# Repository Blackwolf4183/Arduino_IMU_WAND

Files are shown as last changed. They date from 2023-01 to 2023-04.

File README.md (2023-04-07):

# Project Report

# Smart House and Pattern Recognition based on RPI and ESP8266.

## Introduction

In this report I want to showcase a recent project I did to test some practical and not so practical applications on Machine Learning and real world interactions. 

The inspiration for this project came to me when I saw on an online video a Harry Potter’s wand made by Warner Bros, which you could use to perform some “spells” with and it would connect to your smarthome to, for instance, turn on you lights or audio.

I thought the idea was pretty interesting, but I didn’t know the technology they were using to detect the gestures and transform them into orders. 

Still without any knowledge at all about the insights of the wand I supposed It had to use some kind of data gathering and some machine learning algorithm to infer the gestures.

I looked back to a module I had been meaning to use for another project, the MP6050.  The MP6050 is an IMU (Inertial Measurement Unit), which can provide data such as acceleration and angular velocity. 

I thought maybe there was a chance that if a collected the data from the IMU and run it through a Machine Learning Algorithm it could give me back information about which kind of gesture was made.

## Overview of the plan

The basic idea was to stuff some electronics in a custom made wand, so I could transmit wirelessly data from the MP6050 to some kind of server and process that data.

The first challenge was the size of the wand. I have some prior experience with electronics and circuits but none of the kind of making custom PCBs with integrated circuits, so I had to think of the smallest components I could use to get this working. The list is as follows:

- Arduino nano
- ESP8266 - 01 Wifi Module
- On/Off Switch
- 3.7V Lipo Battery
- RGB LED
- LM 1117 (for current reduction to 3.3V)
- 4 330 Ohms Resistors
- Different color cables
- Small Button
- TP4056 (for Lipo charging and discharging)
- 16V 1000**μF** Capacitor

One I had the list of components I made some schematics for the circuit:

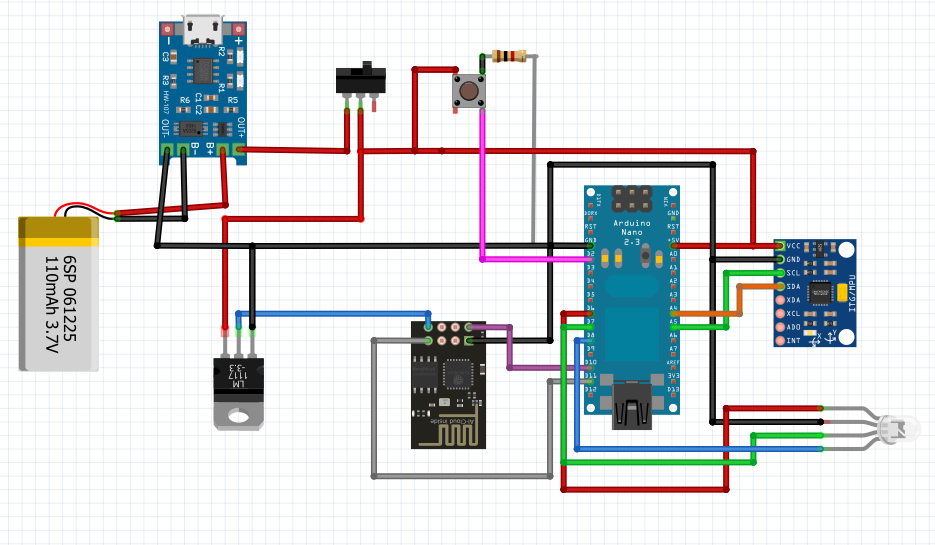
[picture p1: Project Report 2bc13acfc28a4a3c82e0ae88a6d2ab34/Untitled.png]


Having all those components at hand I figured a common size wand from the Harry Potter’s Universe wasn’t going to cut it for the size, so with the help of **Blender** ( 3D Modeling tool) , and a base model I took from a 3D printing website, I altered the model so everything could fit inside nicely.

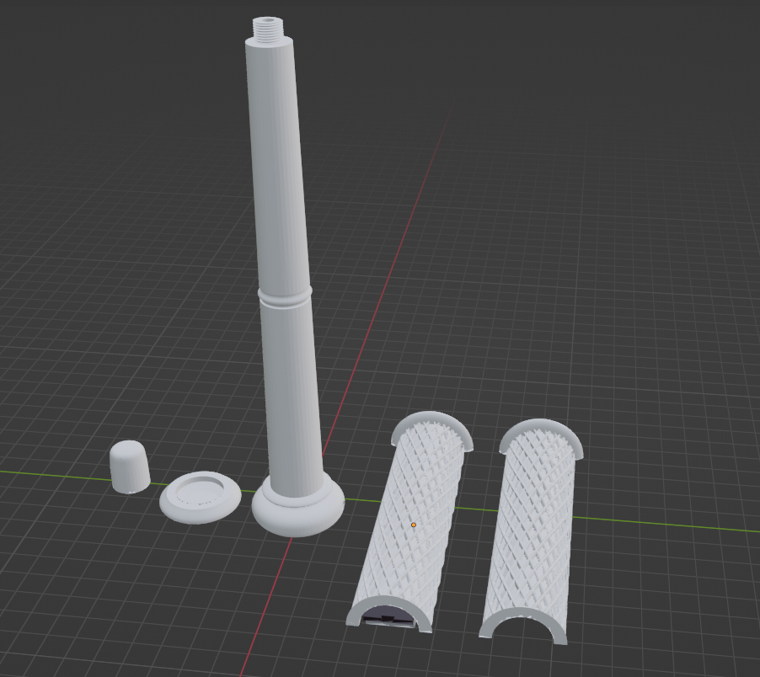
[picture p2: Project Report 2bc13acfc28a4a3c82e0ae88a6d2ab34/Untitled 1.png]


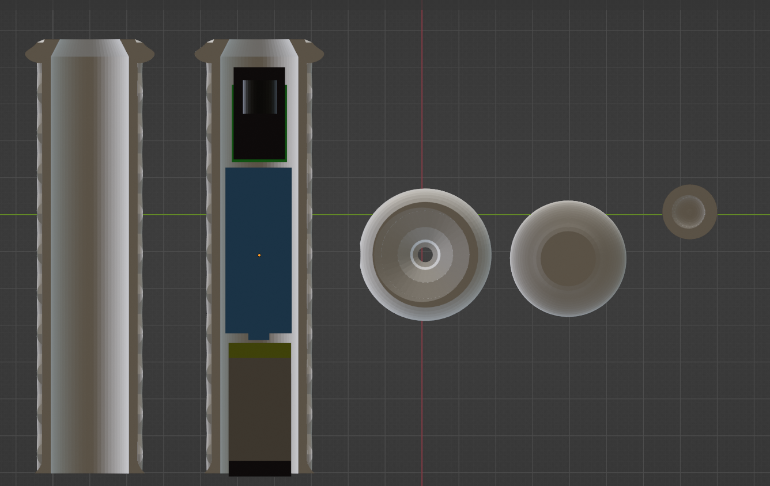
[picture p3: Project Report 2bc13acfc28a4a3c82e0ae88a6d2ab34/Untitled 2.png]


## Wireless Transmission System

The second challenge was to transmit all the data gathered by the wand trough my home wifi network into my **Raspberry Pi**, which would act as a server to manage al the data, and probably host a small webserver in the future. 

### Data format

Most Machine Learning algorithms work best with a fixed size input, so I had to think of a way to always have the same “amount” of data coming out of the ESP8266. The simplest solution to this was to have a button you would press in the wand so that it would start recording a particular amount of values. I estimated that a sequence of 20, 6 value vectors would suit my needs.

In the end I had sequenced that looked something like this:

|  | AccelerationX | AccelerationY | AccelerationZ | AngularX | AngularY | AngularZ |
| --- | --- | --- | --- | --- | --- | --- |
| t0 | 1.2234 | 9.862 | 4.5123 | 0.3523 | 12.903 | 1.643 |
| t1 | 2.2234 | 9.334 | 6.3456 | 0.3236 | 13.347 | 1.393 |
| t2 | 3.2345 | 9.646 | 7.2134 | 0.5523 | 14.384 | 2.234 |
| t3 | 2.2345 | 9.123 | 6.2345 | 0.6553 | 15.522 | 1.931 |
| t4 | 1.7856 | 9.002 | 5.3234 | 0.5563 | 16.332 | 1.000 |
| …. | ….. | …. | …. | … | … | … |
| t19 | 1.2345 | 9.005 | 6.2342 | 0.5523 | 16.342 | 1.123 |

### Setting up de Raspberry Pi

As mentioned earlier, the choice of “server” was the **Raspberry Pi 3B,** I decided to install Raspbian and run a MQTT mosquitto server on it. MQTT is a protocol used for machine-to-machine communication commonly seen in SmartHome applications.

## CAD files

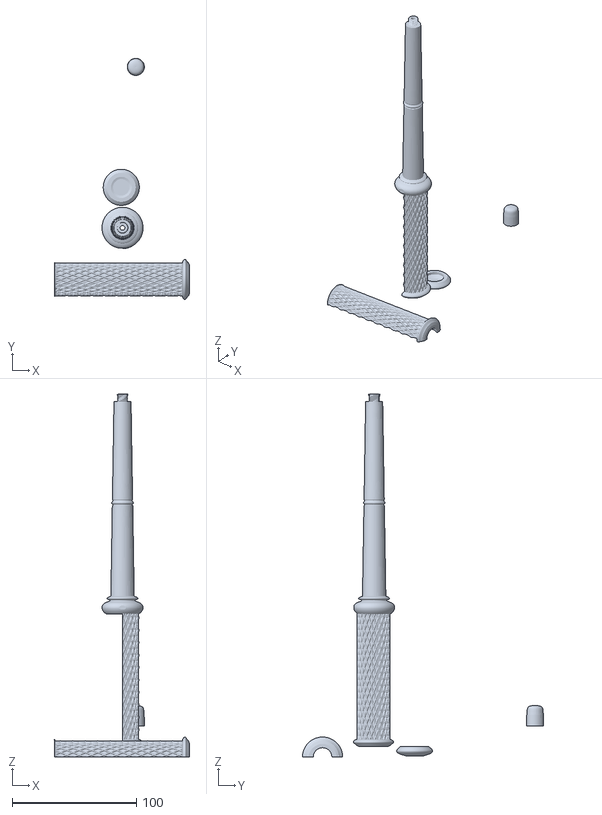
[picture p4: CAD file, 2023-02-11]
Electronics/Compartimento/TestFull.stl
108.7 x 194.2 x 292.3

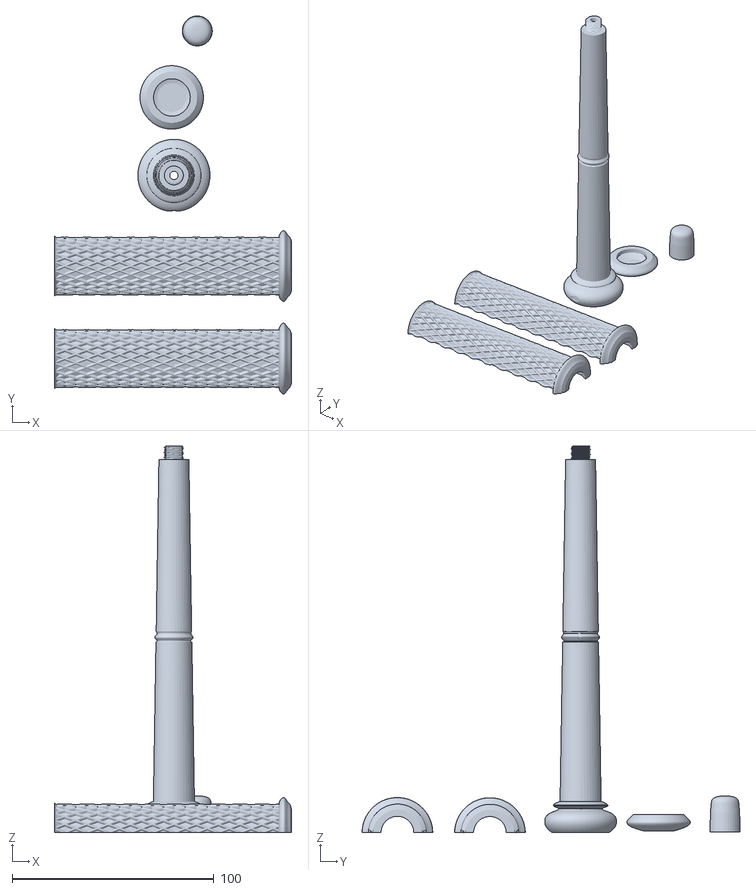
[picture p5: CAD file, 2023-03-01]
Electronics/Compartimento/17-02.stl
117.7 x 187.6 x 191.9

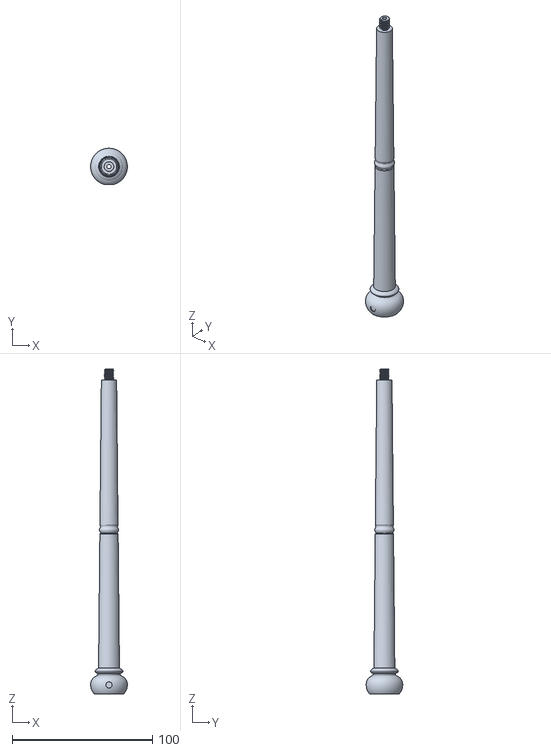
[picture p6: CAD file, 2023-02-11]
Electronics/Compartimento/14-TOP.stl
26.2 x 26.0 x 231.5

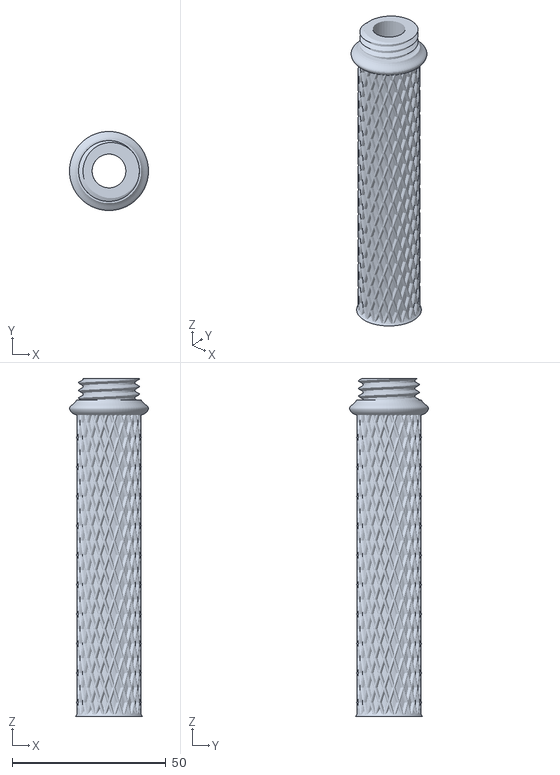
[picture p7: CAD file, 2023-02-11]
Electronics/Compartimento/14-HANDLE.stl
25.7 x 25.7 x 110.0

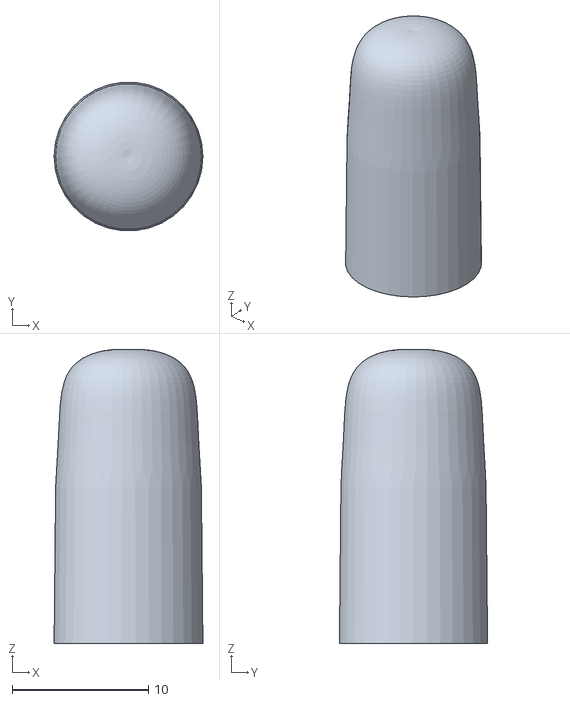
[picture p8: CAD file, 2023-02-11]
Electronics/Compartimento/14-TIP.stl
10.9 x 10.9 x 21.6

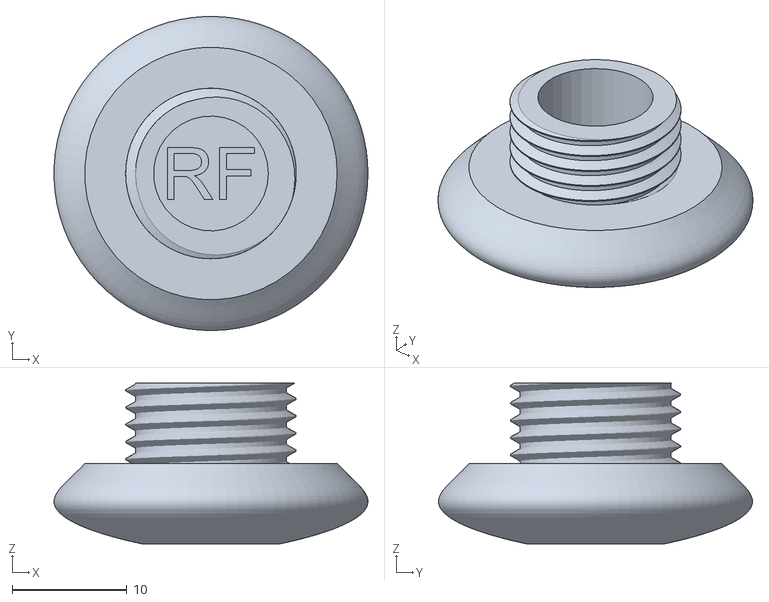
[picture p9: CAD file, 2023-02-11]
Electronics/Compartimento/14-BOTTOM.stl
27.3 x 27.3 x 14.0

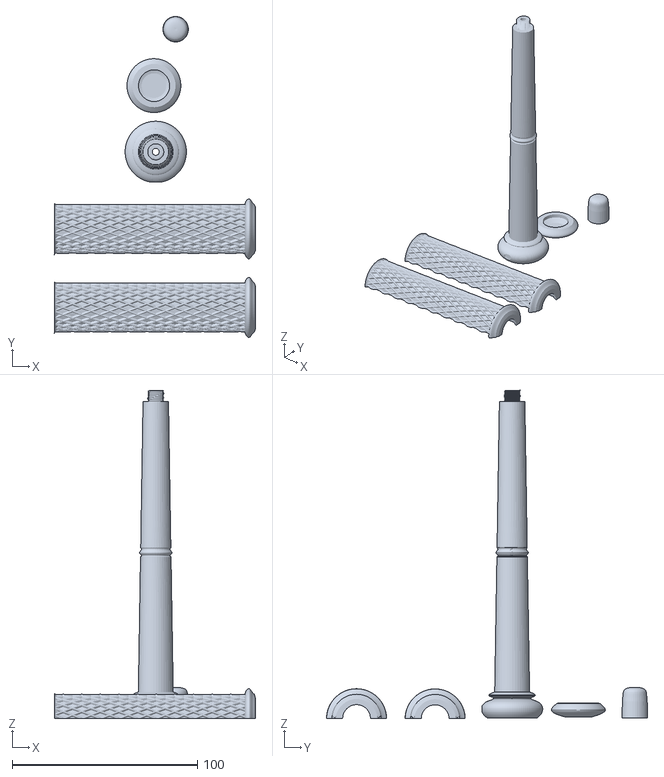
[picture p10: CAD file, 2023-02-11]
Electronics/Compartimento/Resized29.stl
108.7 x 173.2 x 177.2

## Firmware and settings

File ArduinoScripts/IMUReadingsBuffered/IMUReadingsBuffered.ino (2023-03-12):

#include <Adafruit_MPU6050.h>
#include <Adafruit_Sensor.h>
#include <Wire.h>
#include <SoftwareSerial.h>

#define STACK_SIZE 20

const int buttonPin = 2;
//RGB Led
const int redPin = 6;
const int greenPin = 7;
const int bluePin = 8;

//Counter for the amount of sequences sent
int counter = 0;

// Number of colors used for animating, higher = smoother and slower animation)
int numColors = 255;

//Counter to keep track of led color
int ledCounter = 0;
int buttonState = 0;
//Led to notify gesture recording
bool ledOn = false;
//Control wether pushing the button does anything at all
bool canPushButton = true;

Adafruit_MPU6050 mpu;

//Serial communication with Esp8266 Setup
SoftwareSerial mySerial(10, 11);  // RX, TX


//Timers
const unsigned long mainLoopInterval = 100;
const unsigned long rgbInterval = 8;

unsigned long mainLoopTimer;
unsigned long rgbTimer;

//Serial readings variables
const byte numChars = 3;
char receivedChars[numChars];   // an array to store the received data
boolean newData = false;

void setup(void) {

  Serial.println("Starting program...");

  //Timers
  mainLoopTimer = millis();
  rgbTimer = millis();

  //Pin outputs
  pinMode(buttonPin, INPUT);
  pinMode(redPin, OUTPUT);
  pinMode(greenPin, OUTPUT);
  pinMode(bluePin, OUTPUT);

  Serial.begin(115200);
  while (!Serial)
    delay(10);  // will pause Zero, Leonardo, etc until serial console opens


  // Try to initialize!
  if (!mpu.begin()) {
    Serial.println("Failed to find MPU6050 chip");
    while (1) {
      delay(10);
    }
  }
  Serial.println("MPU6050 Found!");

  //Stablish ranges
  mpu.setAccelerometerRange(MPU6050_RANGE_8_G);
  mpu.setGyroRange(MPU6050_RANGE_500_DEG);
  //21 Khz bandwitdh
  mpu.setFilterBandwidth(MPU6050_BAND_21_HZ);
  delay(100);


  //Serial Comunication with esp8266
  mySerial.begin(115200);
  mySerial.println("Starting conexion");
}



void loop() {


  if((millis() - mainLoopTimer) >= mainLoopInterval){

    /* Get new sensor events with the readings */
    //if recording
    if (ledOn) {
      sensors_event_t a, g, temp;
      mpu.getEvent(&a, &g, &temp);

      String values = "";
      values = String(a.acceleration.x) + "," + String(a.acceleration.y) + "," + String(a.acceleration.z) + "," + String(g.gyro.x) + "," + String(g.gyro.y) + "," + String(g.gyro.z);

      //Send over serial
      mySerial.println(values);
      counter++;

      Serial.println(counter);
      Serial.println(values);
      if (counter == STACK_SIZE) {
        //if buffer fills stop
        toggle_led();
        //restart counter
        counter = 0;
      }
      
    }

    //Button
    buttonState = digitalRead(buttonPin);

    if (buttonState == HIGH && canPushButton) {
      Serial.println("Button has been pushed");
      toggle_led();
      mySerial.println("Sequence");
    }


    //#########################################################
    //Serial reading
    recvWithEndMarker();
    
    if (newData == true) {
        Serial.println("Code received: ");
        Serial.println(receivedChars);

        /* 
        Response codes:
        - c1: Operation succesfull
        - c2: Error ocurred
        - c3: Lumos command for wand 
        
        */


        if(!strncmp(receivedChars, "c1",numChars)){
            setColor(0, 255, 0);
            delay(500);
            setColor(0, 0, 0);
            delay(500);
            setColor(0, 255, 0);
            delay(500);
            setColor(0, 0, 0);
            delay(500);
            setColor(0, 255, 0);
            delay(500);
            setColor(0, 0, 0);
 
      
        }else if(!strncmp(receivedChars, "c2",numChars)){
            setColor(255, 0, 0);
            delay(300);
            setColor(0, 0, 0);
            delay(300);
            setColor(255, 0, 0);
            delay(300);
            setColor(0, 0, 0);
            delay(300);
            setColor(255, 0, 0);
            delay(300);
            setColor(0, 0, 0);
            
        }else if(!strncmp(receivedChars, "c3",numChars)){
          setColor(255, 255, 255);
          delay(4000);
          setColor(0, 0, 0);
        }

        newData = false;
    }

    //############################################

    mainLoopTimer = millis();
  }

  if((millis() - rgbTimer) >= rgbInterval){
    //RGB Led
    if(ledOn){
      float colorNumber = ledCounter > numColors ? ledCounter - numColors: ledCounter;
      
      //Led Brightness
      float brightness = 1; // Between 0 and 1 (0 = dark, 1 is full brightness)
      float saturation = 1; // Between 0 and 1 (0 = gray, 1 = full color)
      float hue = (colorNumber / float(numColors)) * 360; // Number between 0 and 360
      long color = HSBtoRGB(hue, saturation, brightness); 
      
      // Get the red, blue and green parts from generated color
      int red = color >> 16 & 255;
      int green = color >> 8 & 255;
      int blue = color & 255;

      setColor(red, green, blue);
      
      // Counter can never be greater then 2 times the number of available colors
      // the colorNumber = line above takes care of counting backwards (nicely looping animation)
      // when counter is larger then the number of available colors
      ledCounter = (ledCounter + 1) % (numColors * 2);
    }else{
      //If led not on just no color
      setColor(0,0,0);
    }

    rgbTimer = millis();
  }

  
}

//Toggle LED
void toggle_led() {
  ledOn = canPushButton;
  canPushButton = !canPushButton;
}

//Set RGB Led Color
void setColor(int redValue, int greenValue, int blueValue) {
  analogWrite(redPin, redValue);
  analogWrite(greenPin, greenValue);
  analogWrite(bluePin, blueValue);
}

long HSBtoRGB(float _hue, float _sat, float _brightness) {
    float red = 0.0;
    float green = 0.0;
    float blue = 0.0;
    
    if (_sat == 0.0) {
        red = _brightness;
        green = _brightness;
        blue = _brightness;
    } else {
        if (_hue == 360.0) {
            _hue = 0;
        }

        int slice = _hue / 60.0;
        float hue_frac = (_hue / 60.0) - slice;

        float aa = _brightness * (1.0 - _sat);
        float bb = _brightness * (1.0 - _sat * hue_frac);
        float cc = _brightness * (1.0 - _sat * (1.0 - hue_frac));
        
        switch(slice) {
            case 0:
                red = _brightness;
                green = cc;
                blue = aa;
                break;
            case 1:
                red = bb;
                green = _brightness;
                blue = aa;
                break;
            case 2:
                red = aa;
                green = _brightness;
                blue = cc;
                break;
            case 3:
                red = aa;
                green = bb;
                blue = _brightness;
                break;
            case 4:
                red = cc;
                green = aa;
                blue = _brightness;
                break;
            case 5:
                red = _brightness;
                green = aa;
                blue = bb;
                break;
            default:
                red = 0.0;
                green = 0.0;
                blue = 0.0;
                break;
        }
    }

    long ired = red * 255.0;
    long igreen = green * 255.0;
    long iblue = blue * 255.0;
    
    return long((ired << 16) | (igreen << 8) | (iblue));
}



void recvWithEndMarker() {
    static byte ndx = 0;
    char endMarker = '\n';
    char rc;
    
    while (mySerial.available() > 0 && newData == false) {
        rc = mySerial.read();

        if (rc != endMarker) {
            receivedChars[ndx] = rc;
            ndx++;
            if (ndx >= numChars) {
                ndx = numChars - 1;
            }
        }
        else {
            receivedChars[ndx] = '\0'; // terminate the string
            ndx = 0;
            newData = true;
        }
    }
}

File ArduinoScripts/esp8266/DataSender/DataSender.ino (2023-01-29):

/*
  Rui Santos
  Complete project details at Complete project details at https://RandomNerdTutorials.com/esp8266-nodemcu-http-get-post-arduino/

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
  Code compatible with ESP8266 Boards Version 3.0.0 or above 
  (see in Tools > Boards > Boards Manager > ESP8266)
*/

#include <ESP8266WiFi.h>
#include <ESP8266HTTPClient.h>
#include <WiFiClient.h>



const char* ssid = "MOVISTAR_9770";
const char* password = "fGYCSuPWiQdAvQvPfhLv";

//Your Domain name with URL path or IP address with path
const char* serverName = "http://192.168.1.120:8000/imu";

// the following variables are unsigned longs because the time, measured in
// milliseconds, will quickly become a bigger number than can be stored in an int.
unsigned long lastTime = 0;
// Timer set to 10 minutes (600000)
//unsigned long timerDelay = 600000;
// Set timer to 5 seconds (5000)
unsigned long timerDelay = 5000;

String values = "";


void setup() {
  Serial.begin(115200);

  WiFi.begin(ssid, password);
  Serial.println("Connecting");
  while(WiFi.status() != WL_CONNECTED) {
    delay(500);
    Serial.print(".");
  }
  Serial.println("");
  Serial.print("Connected to WiFi network with IP Address: ");
  Serial.println(WiFi.localIP());
 
  Serial.println("Timer set to 5 seconds (timerDelay variable), it will take 5 seconds before publishing the first reading.");


}

void loop() {
  //Send an HTTP POST request every 10 minutes
  if ((millis() - lastTime) > timerDelay) {
    //Check WiFi connection status
    if(WiFi.status()== WL_CONNECTED){
      WiFiClient client;
      HTTPClient http;
      
      // Your Domain name with URL path or IP address with path
      http.begin(client, serverName);
  
      // If you need Node-RED/server authentication, insert user and password below
      //http.setAuthorization("REPLACE_WITH_SERVER_USERNAME", "REPLACE_WITH_SERVER_PASSWORD");
  
      // Specify content-type header
      http.addHeader("Content-Type", "application/json");
       

      //TODO: inicializar serial para lectura de arduino
      if(Serial.available() > 0 ){
        values = Serial.readString();
      }

      //"{\"values\":\"FUNCIONA\"}"
      String json = "{\"values\":" + values + "}";

      // Send HTTP POST request
      int httpResponseCode = http.POST(json);
      
      // If you need an HTTP request with a content type: application/json, use the following:
      //http.addHeader("Content-Type", "application/json");
      //int httpResponseCode = http.POST("{\"api_key\":\"tPmAT5Ab3j7F9\",\"sensor\":\"BME280\",\"value1\":\"24.25\",\"value2\":\"49.54\",\"value3\":\"1005.14\"}");

      // If you need an HTTP request with a content type: text/plain
      //http.addHeader("Content-Type", "text/plain");
      //int httpResponseCode = http.POST("Hello, World!");
     
      Serial.print("HTTP Response code: ");
      Serial.println(httpResponseCode);
        
      // Free resources
      http.end();
    }
    else {
      Serial.println("WiFi Disconnected");
    }
    lastTime = millis();
  }
}

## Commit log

2022-12-14 Python and arduino testing
    [test_data.csv]
2022-12-16 Graph plotting in python
    [test_data.csv]
2022-12-18 Data gathering and processing
    [Lumos1.csv, Lumos2.csv, Lumos3.csv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]
2022-12-18 more things
    [Lumos1.csv, Lumos2.csv, Lumos3.csv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]
2022-12-19 More work on cnn
    [test1.csv, test2.csv, test3.csv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]
2022-12-21 RealTime python implementation for CNN
    [test_data.csv]
2023-01-29 Somewhat functional mqtt conextion to raspberry pi and transmision of data
2023-01-29 Working sensor transmision through Esp8266
2023-02-11 3D Models and schematics
    [14-BOTTOM.stl, 14-HANDLE.stl, 14-TIP.stl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]
2023-02-13 RGB Led code without rainbow change
2023-02-13 Implemented Rainbow Change on RGB Led
2023-03-01 RPI reordering code
    [17-02.stl, Best.stl, fullwand.stl]
2023-03-12 New model dataset (50 images/gesture)
    [14-BOTTOM.stl, 14-HANDLE.stl, 14-TIP.stl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]
2023-03-14 added data proccessing and flow
2023-03-21 Working script to remotely turn len on with Esp8266
    [Harry_Potter_Connector.stl, harry-potter-wand-split-2.stl]
2023-05-25 Modifications to arduino script
